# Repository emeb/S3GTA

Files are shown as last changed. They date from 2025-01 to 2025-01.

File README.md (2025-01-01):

# S3GTA
A Eurorack effects module based on the ESP32S3

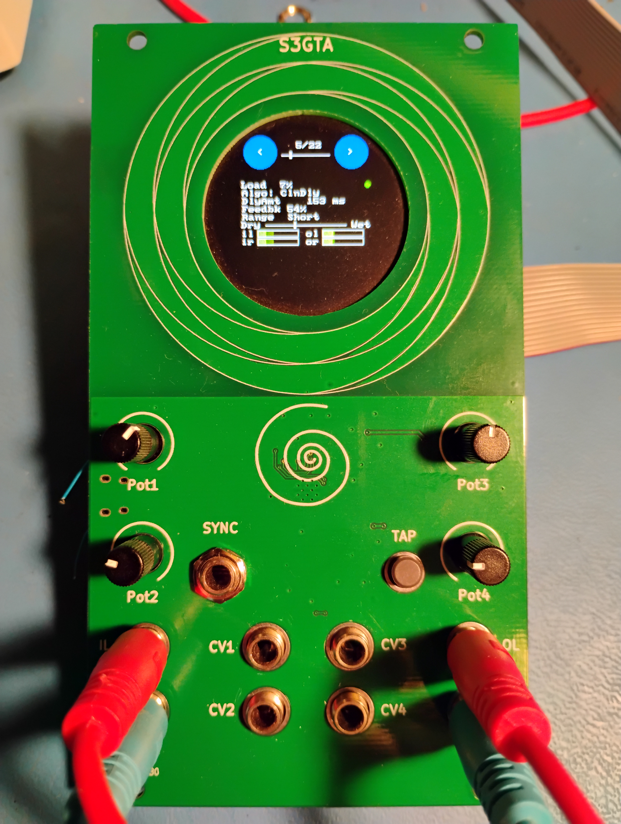
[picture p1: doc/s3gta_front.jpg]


## Abstract
This project builds on my previous ESP32S2 design:

https://github.com/emeb/ESP32S2_Audio

taking it further with a circular LCD, touch sensing and more CV inputs. It's
based on an ESP32S3 with 4MB flash and 2MB PSRAM in the package, as well as
dual CPU cores to potentially provide more DSP bandwidth.

### What's with the name?
I'm terrible at coming up with catchy names for my projects and this one is no
departure from that. It breaks down thus:
* S3 from the ESP32S3 processor
* G from the GC9A01 LCD
* T from the circular touch sensor
* A from audio I/O

## Hardware
The hardware consists of two PCBs - a front-panel board that provides the main
Eurorack user interface including a 240x240 circular LCD with a circular touch
sensor surrounding it and the MCU & audio codec, coupled with a back board that
includes the Eurorack power as well as audio and CV interfaces for the front-panel.

The front-panel PCB contains the following components:
* ESP32-S3FH4R2 MCU with 4MB flash and 2MB PSRAM integrated in the package
* WM8731 I2S audio codec
* 4 pad proportional circular touch sensor
* 4 CVs, stereo in/out and sync + button interfaces to back board.
* optional USB and Qwicc connectors

The back board has
* Standard Eurorack 16-pin shrouded power connector
* Four +/-5V CV inputs and associated analog signal conditioning
* Four offset pots for the CVs
* Two +/-7V Audio inputs and associated analog signal conditioning 
* Two +/-7V Audio outputs and associated analog drivers
* Tap tempo button
* Sync input jack

## Firmware
A demonstration firmware is included that exercises all of the capabilities of
the system, including the LCD, UI button, CV inputs and stereo audio I/O. It is
a basic multi-effects unit that supports a complement of audio DSP algorithms
that are easily extended by adding standardized modules to a data structure.
As provided here just three algorithms are available:
* Simple pass-thru with no processing
* Simple gain control
* Lowpass, Highpass and Bandpass filters
* Basic "clean delay" with crossfaded deglitching during delay changes.

Other algorithms have been tested including phasers, flangers, frequency shifters,
resampling delays and reverbs, but these are not publicly released at this time.

## Findings
The ESP32Ss is not bad for doing audio and the I2S driver in ESP-IDF V5.2.3 does
include good support for realtime audio processing. There are a few hiccups in
the way it works that are commented in the source code, but overall it does a
good job of supporting audio effects processing.

I found that in general the DSP on the ESP32S3 was usable, although not as
efficient as on ARM processors. Some algorithms showed significantly higher CPU
loading on the ESP32S3 than on ARM Cortex M7, even accounting for clock speed
differences. Studying the disassembly of the object code suggests that the full
DSP capability of the ESP32S3 Xtensa CPU ISA isn't being brought to bear by the
GCC compiler - for example the available multiply-accumulate instructions were
not used in cases where they may have reduced overall instruction counts.

## Future work
The UI is fairly primitive and doesn't make effective use of the circular touch
sensor. In the initial release there are only two "soft buttons" that employ
the touch sensor to select the current algorithm and this could be extended
to allow more soft buttons, deeper menuing and even continuously variable
adjustmets for things like on-board modulation.

The graphic elements on the circular LCD are also pretty tiny and hard to read
while also not taking full advantage of the available LCD area. It would be
interesting to "lean in" to the round nature of the display with more arcs
and circular UI elements. Fatter lines and larger fonts would help a lot too.
One option is to ditch the home-made graphics library I used here and try to
leverage LVGL which is available as an external module in ESP IDF - I did a
bit of research into this at the outset but went with my existing graphics
for ease of porting older code.

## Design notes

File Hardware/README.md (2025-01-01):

# S3GTA Hardware
This directory contains the Kicad designs for the front and back PCBs

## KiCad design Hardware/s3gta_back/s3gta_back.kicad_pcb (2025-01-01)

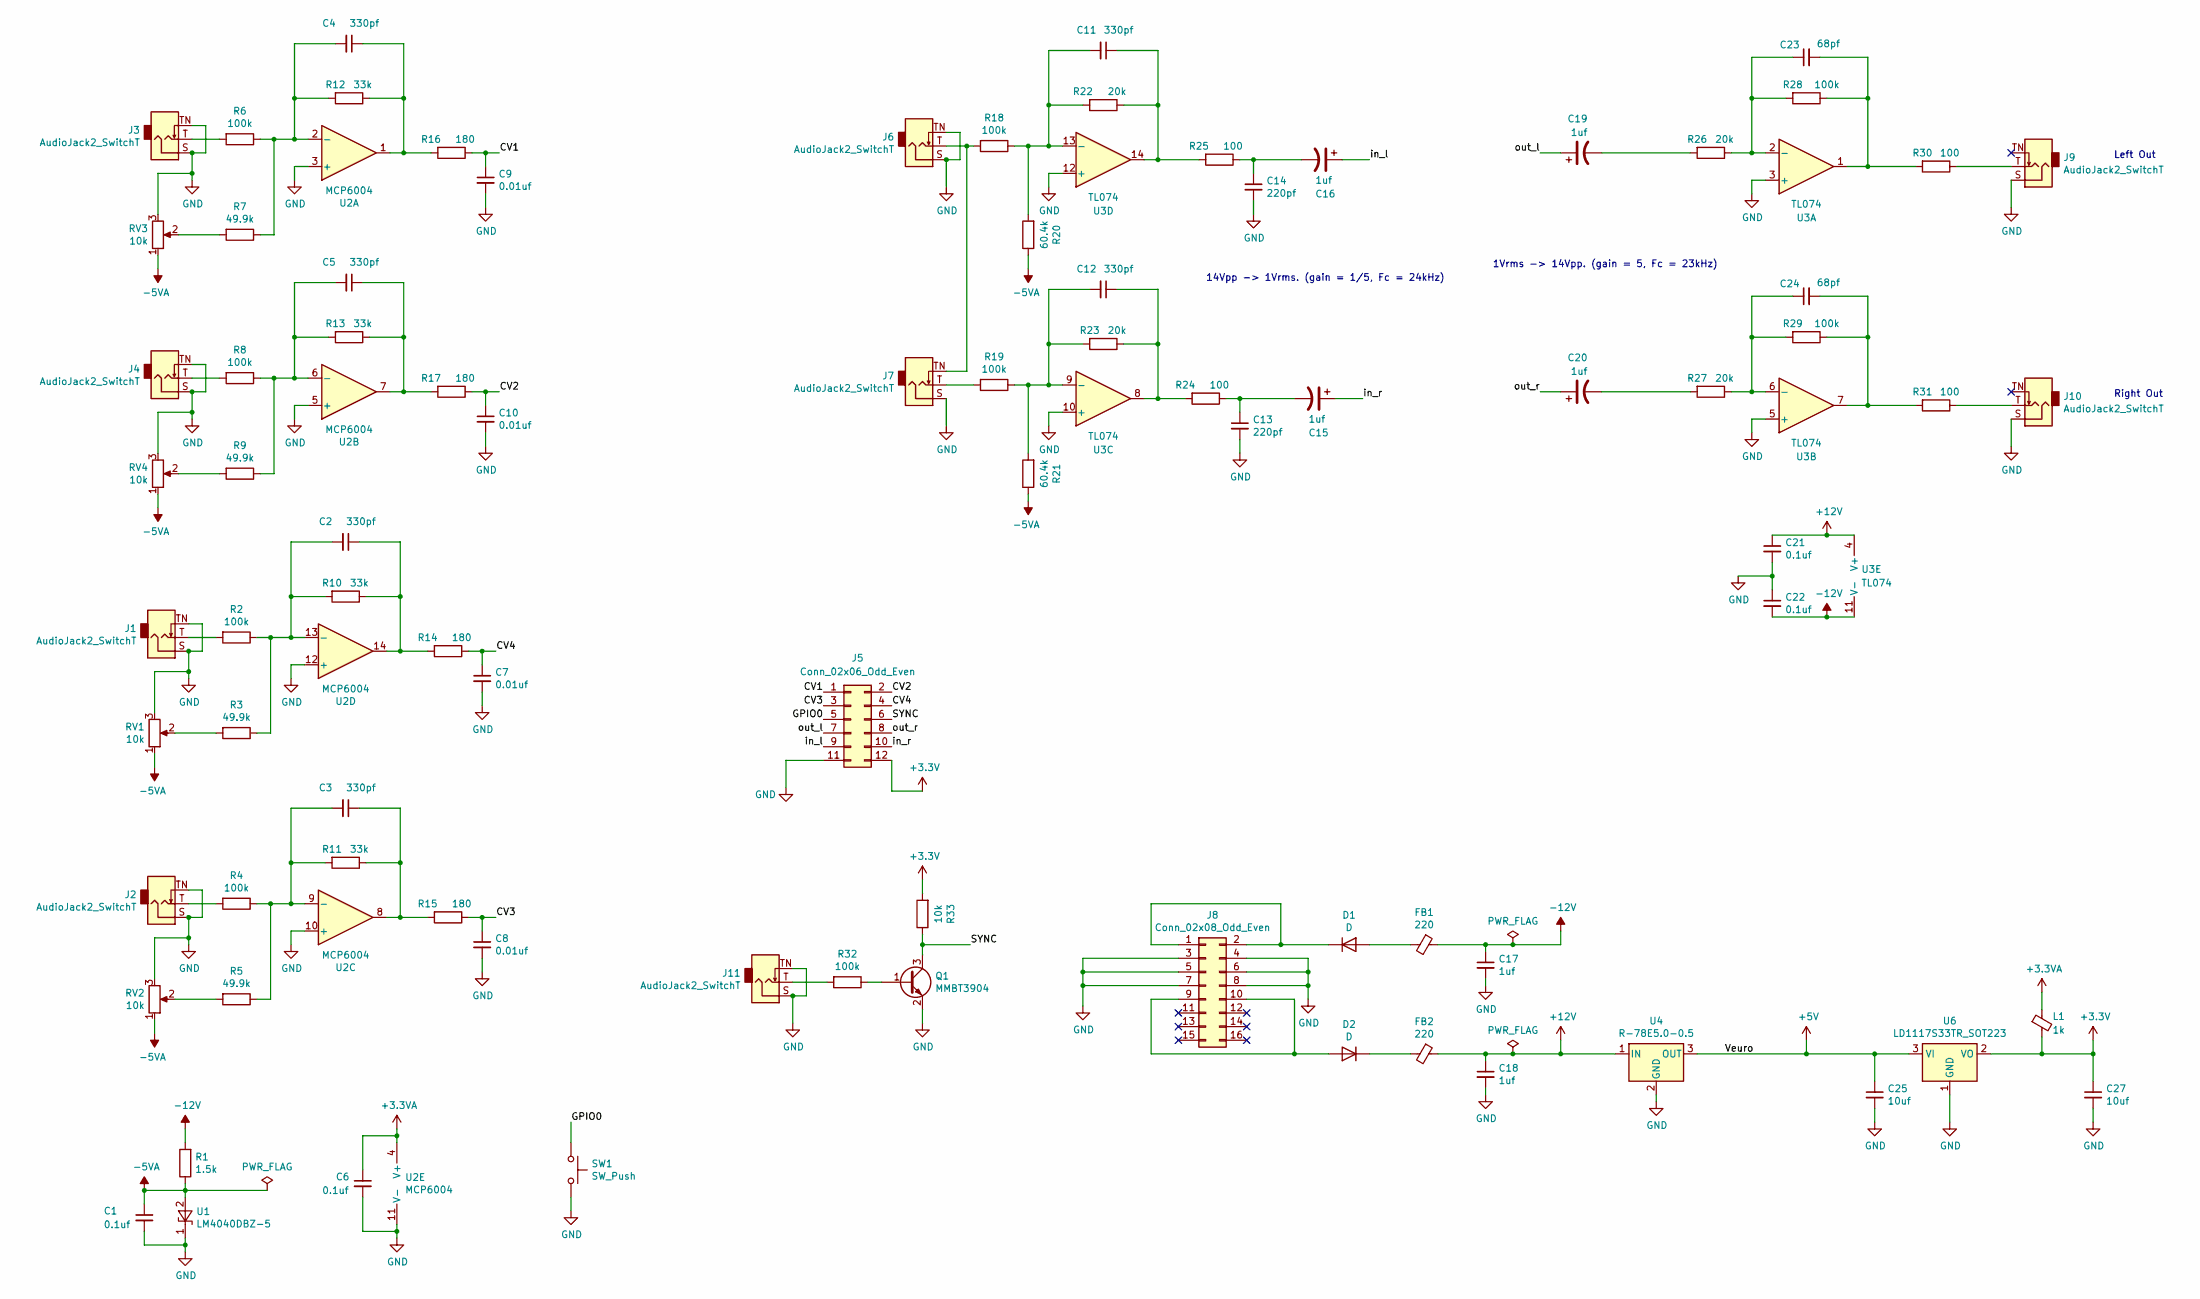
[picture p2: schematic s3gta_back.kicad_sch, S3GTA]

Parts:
C1, C6, C21, C22: 0.1uf; C_0603_1608Metric
C2, C3, C4, C5, C11, C12: 330pf; C_0603_1608Metric
C7, C8, C9, C10: 0.01uf; C_0603_1608Metric
C13, C14: 220pf; C_0603_1608Metric
C15, C16, C19, C20: 1uf; CP_Elec_4x5.3
C17, C18: 1uf; C_0603_1608Metric
C23, C24: 68pf; C_0603_1608Metric
C25, C27: 10uf; C_0805_2012Metric
D1, D2: D; D_SMA
FB1, FB2: 220; L_0805_2012Metric
J1, J2, J3, J4, J6, J7, J9, J10, J11: AudioJack2_SwitchT; Jack_3.5mm_QingPu_WQP-PJ398SM_Vertical_CircularHoles
J5: Conn_02x06_Odd_Even; PinSocket_2x06_P2.54mm_Vertical
J8: Conn_02x08_Odd_Even; con16_2X8_S4_TEC
L1: 1k; L_0603_1608Metric
Q1: MMBT3904; SOT-23
R1: 1.5k; R_0603_1608Metric
R2, R4, R6, R8, R18, R19, R28, R29, R32: 100k; R_0603_1608Metric
R3, R5, R7, R9: 49.9k; R_0603_1608Metric
R10, R11, R12, R13: 33k; R_0603_1608Metric
R14, R15, R16, R17: 180; R_0603_1608Metric
R20, R21: 60.4k; R_0603_1608Metric
R22, R23, R26, R27: 20k; R_0603_1608Metric
R24, R25, R30, R31: 100; R_0603_1608Metric
R33: 10k; R_0603_1608Metric
RV1, RV2, RV3, RV4: 10k; R0904N
SW1: SW_Push; SW_PUSH_6mm
U1: LM4040DBZ-5; SOT-23
U2: MCP6004; SOIC-14_3.9x8.7mm_P1.27mm
U3: TL074; SOIC-14_3.9x8.7mm_P1.27mm
U4: R-78E5.0-0.5; Converter_DCDC_RECOM_R-78E-0.5_THT
U6: LD1117S33TR_SOT223; SOT-223-3_TabPin2

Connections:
+3.3V: C27.1, J5.12, L1.2, R33.2, U6.2 (VO)
+3.3VA: C6.1, L1.1, U2.4 (V+)
+5V: C25.1, U4.3 (OUT), U6.3 (VI)
+12V: C18.1, C21.1, FB2.1, U3.4 (V+), U4.1 (IN)
-5VA: C1.1, R1.1, R20.1, R21.1, RV1.1, RV2.1, RV3.1, RV4.1, U1.2 (A)
-12V: C17.1, C22.2, FB1.1, R1.2, U3.11 (V-)
/CV1: C9.1, J5.1, R16.1
/CV2: C10.1, J5.2, R17.1
/CV3: C8.1, J5.3, R15.1
/CV4: C7.1, J5.4, R14.1
/GPIO0: J5.5, SW1.1
/SYNC: J5.6, Q1.3 (C), R33.1
/in_l: C16.1, J5.9
/in_r: C15.1, J5.10
/out_l: C19.1, J5.7
/out_r: C20.1, J5.8
GND: C1.2, C6.2, C7.2, C8.2, C9.2, C10.2, C13.2, C14.2, C17.2, C18.2, C21.2, C22.1, C25.2, C27.2, J1.S, J1.TN, J2.S, J2.TN, J3.S, J3.TN, J4.S, J4.TN, J5.11, J6.S, J6.TN, J7.S, J8.3, J8.4, J8.5, J8.6, J8.7, J8.8, J9.S, J10.S, J11.S, J11.TN, Q1.2 (E), RV1.3, RV2.3, RV3.3, RV4.3, SW1.2, U1.1 (K), U2.3 (+), U2.5 (+), U2.10 (+), U2.11 (V-), U2.12 (+), U3.3 (+), U3.5 (+), U3.10 (+), U3.12 (+), U4.2 (GND), U6.1 (GND)
unnamed: C2.1, R10.1, R14.2, U2.14
unnamed: C3.1, R11.1, R15.2, U2.8
unnamed: C4.1, R12.1, R16.2, U2.1
unnamed: C5.1, R13.1, R17.2, U2.7
unnamed: C11.1, R22.1, R25.2, U3.14
unnamed: C12.1, R23.1, R24.2, U3.8
unnamed: C13.1, C15.2, R24.1
unnamed: C14.1, C16.2, R25.1
unnamed: C19.2, R26.2
unnamed: C20.2, R27.2
unnamed: C23.2, R28.1, R30.2, U3.1
unnamed: C24.2, R29.1, R31.2, U3.7
unnamed: D1.2 (A), FB1.2
unnamed: D1.1 (K), J8.1, J8.2
unnamed: D2.2 (A), J8.9, J8.10
unnamed: D2.1 (K), FB2.2
unnamed: J1.T, R2.2
unnamed: J2.T, R4.2
unnamed: J3.T, R6.2
unnamed: J4.T, R8.2
unnamed: J6.T, J7.TN, R18.2
unnamed: J7.T, R19.2
unnamed: J9.T, R30.1
unnamed: J10.T, R31.1
unnamed: J11.T, R32.2
unnamed: Q1.1 (B), R32.1
unnamed: R3.2, RV1.2
unnamed: R5.2, RV2.2
unnamed: R7.2, RV3.2
unnamed: R9.2, RV4.2
unnamed: C4.2, R6.1, R7.1, R12.2, U2.2 (-)
unnamed: C5.2, R8.1, R9.1, R13.2, U2.6 (-)
unnamed: C3.2, R4.1, R5.1, R11.2, U2.9 (-)
unnamed: C2.2, R2.1, R3.1, R10.2, U2.13 (-)
unnamed: C23.1, R26.1, R28.2, U3.2 (-)
unnamed: C24.1, R27.1, R29.2, U3.6 (-)
unnamed: C12.2, R19.1, R21.2, R23.2, U3.9 (-)
unnamed: C11.2, R18.1, R20.2, R22.2, U3.13 (-)

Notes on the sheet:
1Vrms -> 14Vpp. (gain = 5, Fc = 23kHz)
14Vpp -> 1Vrms. (gain = 1/5, Fc = 24kHz)
Right Out
Left Out

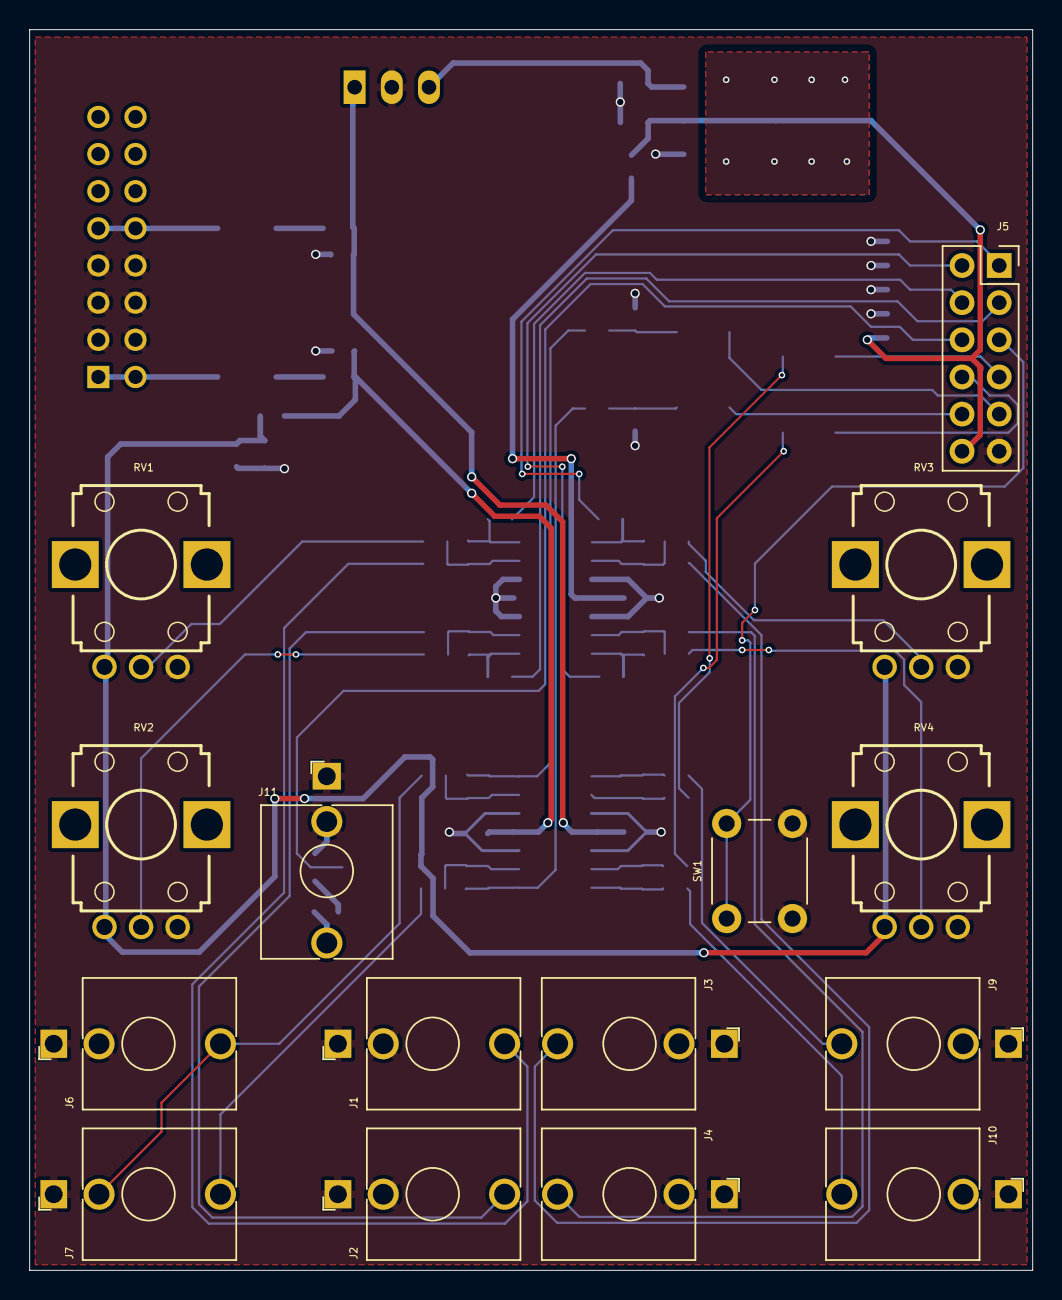
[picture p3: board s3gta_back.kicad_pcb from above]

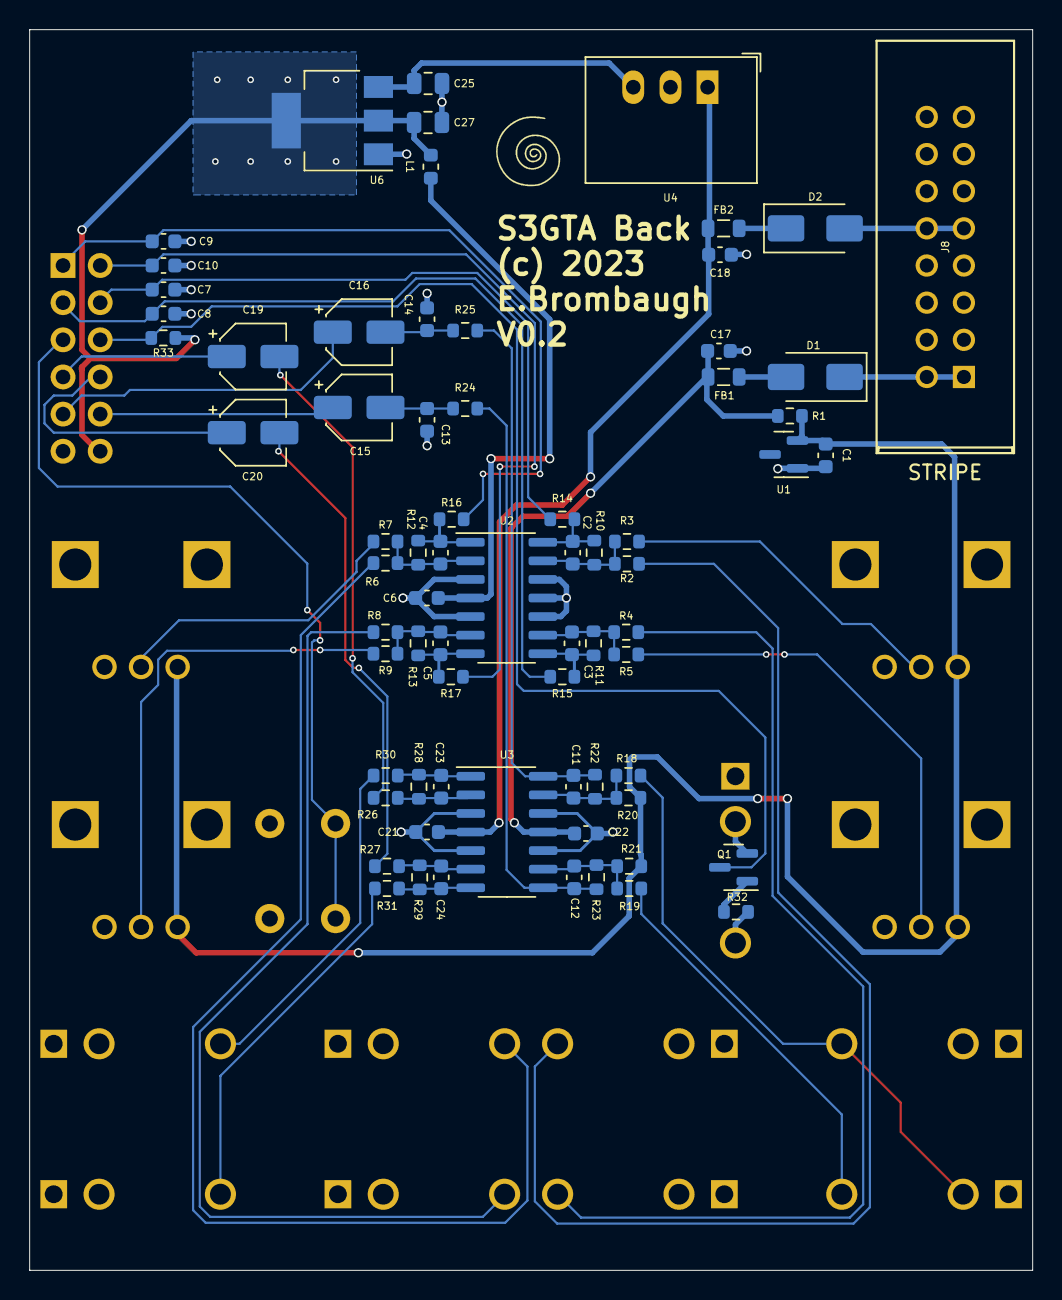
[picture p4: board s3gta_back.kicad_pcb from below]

Board: 2 copper layers, 68.6 x 84.8 mm, 87 parts (72 on the bottom side), 55 nets.

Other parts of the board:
Ref**: Val**; avatar_small

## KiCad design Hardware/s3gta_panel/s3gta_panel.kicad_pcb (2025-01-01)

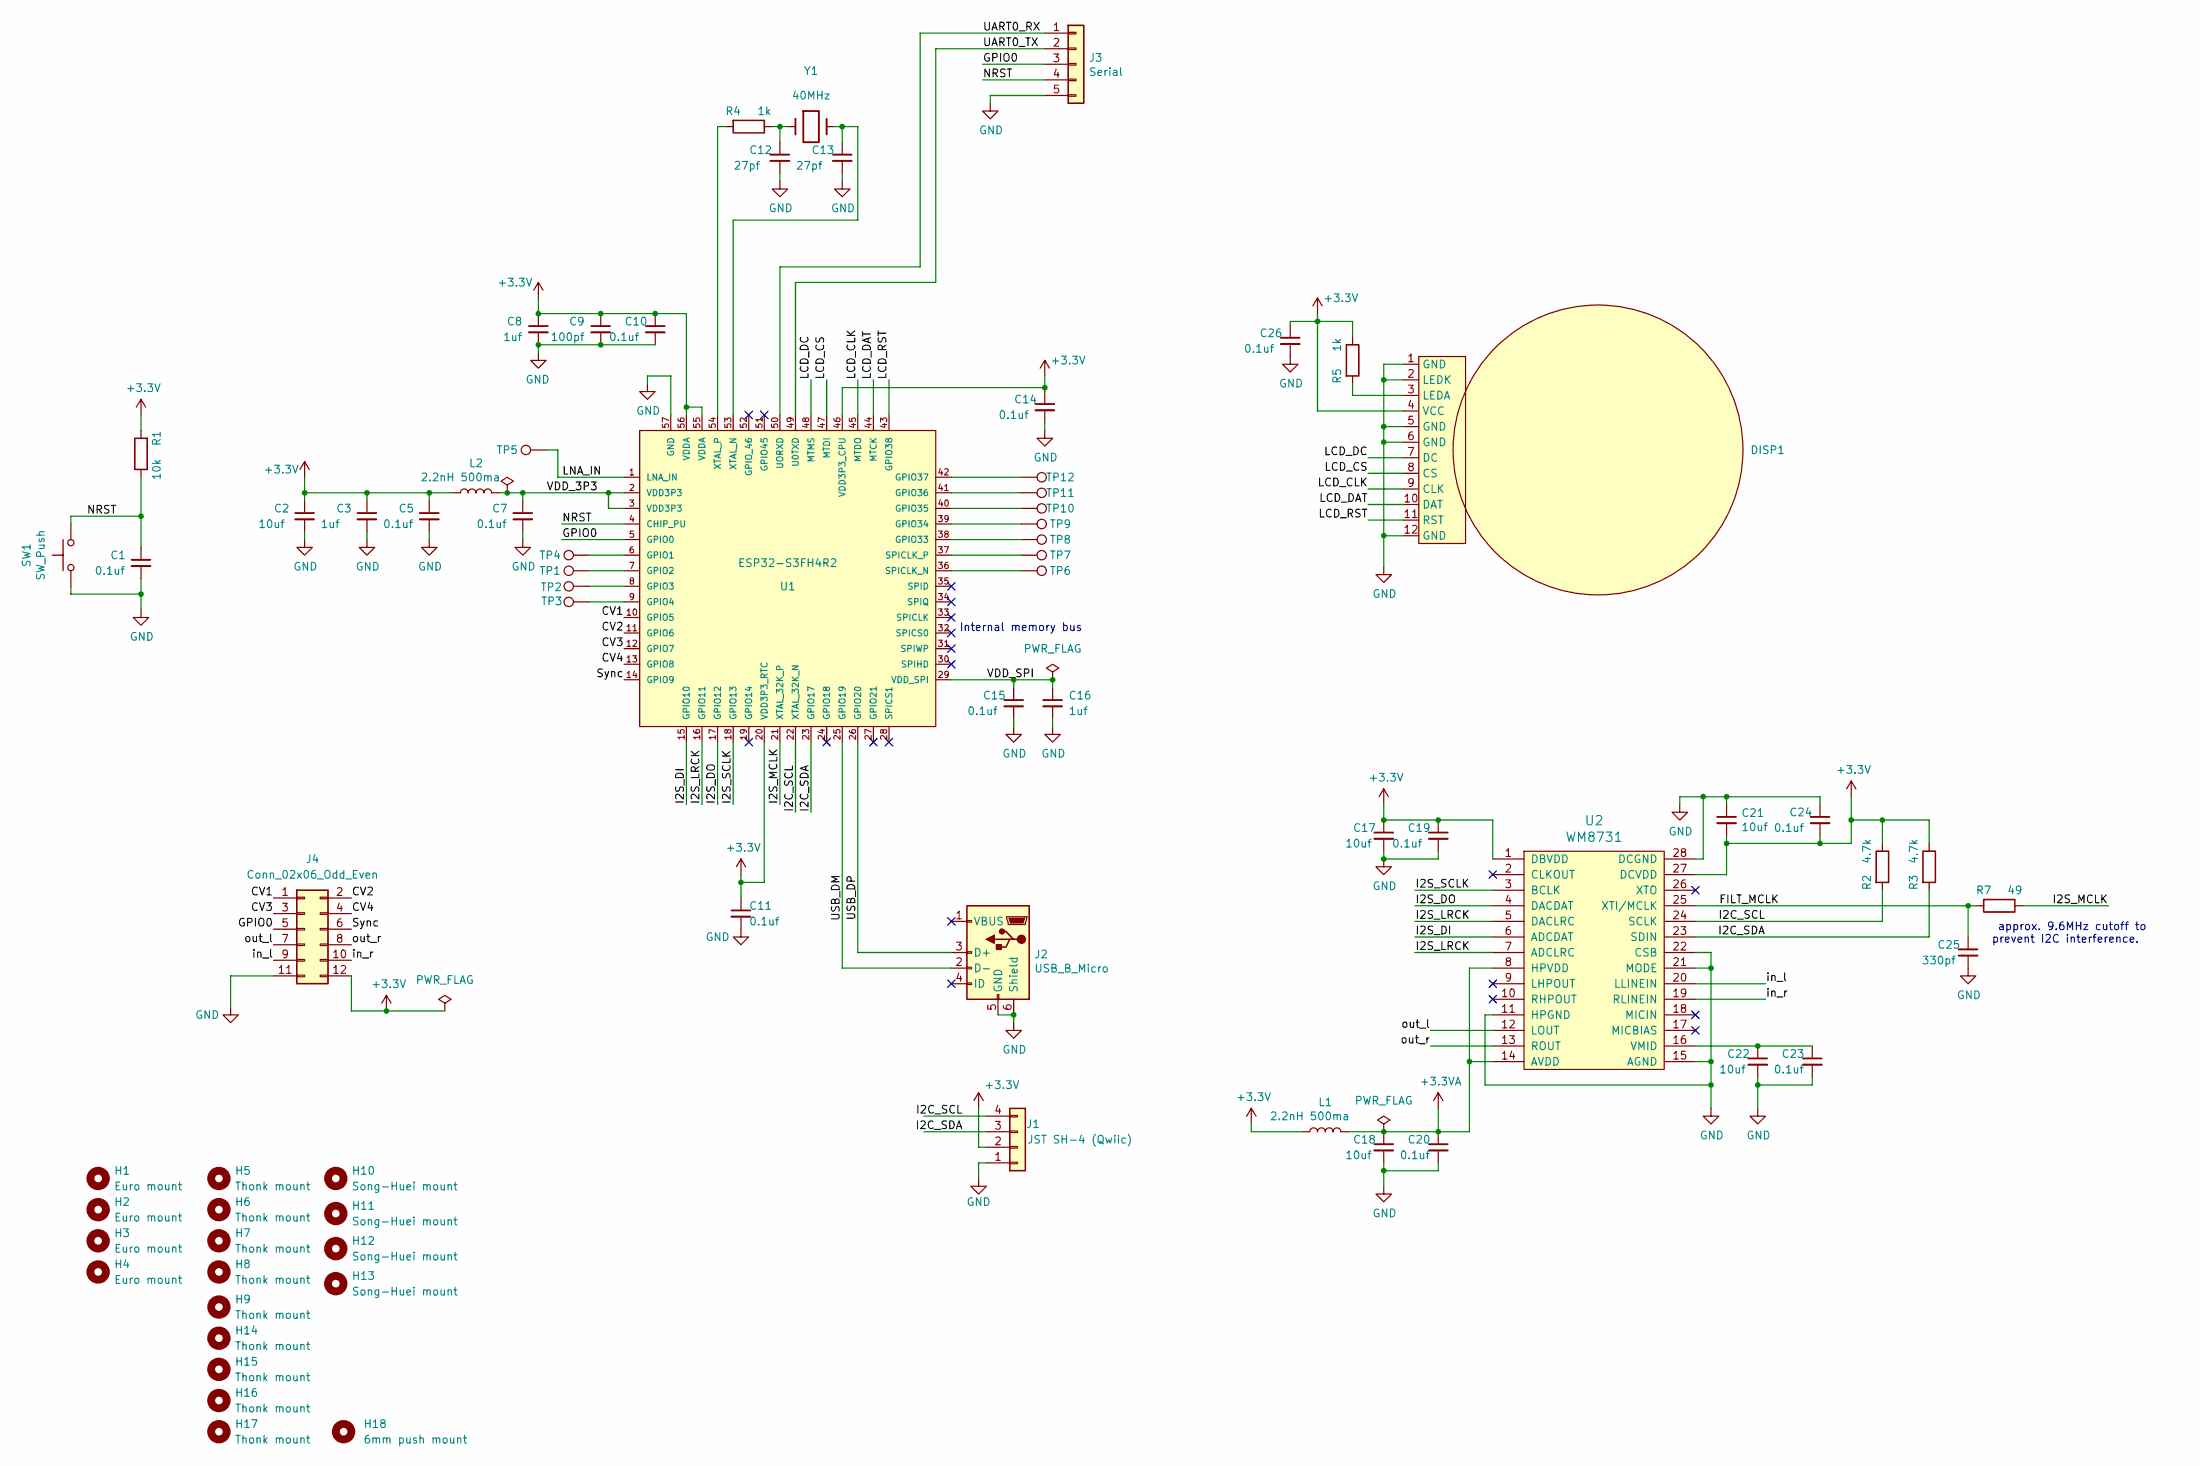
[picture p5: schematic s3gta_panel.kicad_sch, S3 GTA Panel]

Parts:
C1, C5, C7, C10, C11, C14, C15, C19, C20, C23, C24, C26: 0.1uf; C_0603_1608Metric
C2, C17, C18, C21, C22: 10uf; C_0805_2012Metric
C3, C8, C16: 1uf; C_0603_1608Metric
C9: 100pf; C_0603_1608Metric
C12, C13: 27pf; C_0603_1608Metric
C25: 330pf; C_0603_1608Metric
DISP1: Round_LCD_GC9A01
H1, H2, H3, H4: Euro mount; Mount_Hole_Euro_Rack
H5, H6, H7, H8, H9, H14, H15, H16, H17: Thonk mount; Mount_Hole_Thonk
H10, H11, H12, H13: Song-Huei mount; Mount_Hole_Song_Huei
H18: 6mm push mount; Mount_Hole_Toggle_Submini
J1: JST SH-4 (Qwiic); JST_SH_SM04B-SRSS-TB_04x1.00mm_Angled
J2: USB_B_Micro; USB_Micro-B_10103594-0001LF_actual_outline
J3: Serial; Harwin_M20-89005xx_1x05_P2.54mm_Horizontal
J4: Conn_02x06_Odd_Even; PinHeader_2x06_P2.54mm_Vertical_SMD
L1, L2: 2.2nH 500ma; C_0603_1608Metric
R1: 10k; R_0603_1608Metric
R2, R3: 4.7k; R_0603_1608Metric
R4, R5: 1k; R_0603_1608Metric
R7: 49; R_0603_1608Metric
SW1: SW_Push; SW_Push_1P1T_NO_CK_KMR2
TP1, TP2, TP3, TP4: TouchPad; quarter_touch
TP5, TP6, TP7, TP8, TP9, TP10, TP11, TP12: TouchPad; TestPoint_Pad_D0.5mm
U1: ESP32-S3FH4R2; ESP32-S3; mouser part number 356-ESP32-S2; digikey description RX TXRX MOD WIFI SURFACE MOUNT
U2: WM8731; SSOP-28_5.3x10.2mm_P0.65mm
Y1: 40MHz; Crystal_SMD_3225-4Pin_3.2x2.5mm

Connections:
+3.3V: C2.1, C3.1, C5.1, C8.1, C9.1, C10.1, C11.1, C14.1, C17.1, C19.1, C21.2, C24.2, C26.1, DISP1.4 (VCC), J1.2, J4.12, L1.1, L2.1, R1.2, R2.1, R3.1, R5.1, U1.20 (VDD3P3_RTC), U1.46 (VDD3P3_CPU), U1.55 (VDDA), U1.56 (VDDA), U2.1 (DBVDD), U2.27 (DCVDD)
+3.3VA: C18.1, C20.1, L1.2, U2.8 (HPVDD), U2.14 (AVDD)
/CV1: J4.1, U1.10 (GPIO5)
/CV2: J4.2, U1.11 (GPIO6)
/CV3: J4.3, U1.12 (GPIO7)
/CV4: J4.4, U1.13 (GPIO8)
/FILT_MCLK: C25.1, R7.2, U2.25 (XTI/MCLK)
/GPIO0: J3.3, J4.5, U1.5 (GPIO0)
/I2C_SCL: J1.4, R2.2, U1.22 (XTAL_32K_N), U2.24 (SCLK)
/I2C_SDA: J1.3, R3.2, U1.23 (GPIO17), U2.23 (SDIN)
/I2S_DI: U1.15 (GPIO10), U2.6 (ADCDAT)
/I2S_DO: U1.17 (GPIO12), U2.4 (DACDAT)
/I2S_LRCK: U1.16 (GPIO11), U2.5 (DACLRC), U2.7 (ADCLRC)
/I2S_MCLK: R7.1, U1.21 (XTAL_32K_P)
/I2S_SCLK: U1.18 (GPIO13), U2.3 (BCLK)
/LCD_CLK: DISP1.9 (CLK), U1.45 (MTDO)
/LCD_CS: DISP1.8 (CS), U1.47 (MTDI)
/LCD_DAT: DISP1.10 (DAT), U1.44 (MTCK)
/LCD_DC: DISP1.7 (DC), U1.48 (MTMS)
/LCD_RST: DISP1.11 (RST), U1.43 (GPIO38)
/LNA_IN: TP5.1, U1.1 (LNA_IN)
/NRST: C1.1, J3.4, R1.1, SW1.1, U1.4 (CHIP_PU)
/Sync: J4.6, U1.14 (GPIO9)
/UART0_RX: J3.1, U1.50 (UORXD)
/UART0_TX: J3.2, U1.49 (U0TXD)
/USB_DM: J2.2 (D-), U1.25 (GPIO19)
/USB_DP: J2.3 (D+), U1.26 (GPIO20)
/VDD_3P3: C7.1, L2.2, U1.2 (VDD3P3), U1.3 (VDD3P3)
/VDD_SPI: C15.1, C16.1, U1.29 (VDD_SPI)
/in_l: J4.9, U2.20 (LLINEIN)
/in_r: J4.10, U2.19 (RLINEIN)
/out_l: J4.7, U2.12 (LOUT)
/out_r: J4.8, U2.13 (ROUT)
GND: C1.2, C2.2, C3.2, C5.2, C7.2, C8.2, C9.2, C10.2, C11.2, C12.2, C13.2, C14.2, C15.2, C16.2, C17.2, C18.2, C19.2, C20.2, C21.1, C22.2, C23.2, C24.1, C25.2, C26.2, DISP1.1 (GND), DISP1.2 (LEDK), DISP1.5 (GND), DISP1.6 (GND), DISP1.12 (GND), J1.1, J2.5 (GND), J2.6 (Shield), J3.5, J4.11, SW1.2, U1.57 (GND), U2.11 (HPGND), U2.15 (AGND), U2.21 (MODE), U2.22 (CSB), U2.28 (DCGND)
unnamed: C12.1, R4.1, Y1.1
unnamed: DISP1.3 (LEDA), R5.2
unnamed: TP4.1, U1.6 (GPIO1)
unnamed: TP1.1, U1.7 (GPIO2)
unnamed: TP2.1, U1.8 (GPIO3)
unnamed: TP3.1, U1.9 (GPIO4)
unnamed: TP8.1, U1.38 (GPIO33)
unnamed: TP9.1, U1.39 (GPIO34)
unnamed: TP10.1, U1.40 (GPIO35)
unnamed: TP11.1, U1.41 (GPIO36)
unnamed: TP12.1, U1.42 (GPIO37)
unnamed: TP6.1, U1.36 (SPICLK_N)
unnamed: TP7.1, U1.37 (SPICLK_P)
unnamed: C13.1, U1.53 (XTAL_N), Y1.3
unnamed: R4.2, U1.54 (XTAL_P)
unnamed: C22.1, C23.1, U2.16 (VMID)

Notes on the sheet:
Internal memory bus
approx. 9.6MHz cutoff to prevent I2C interference.

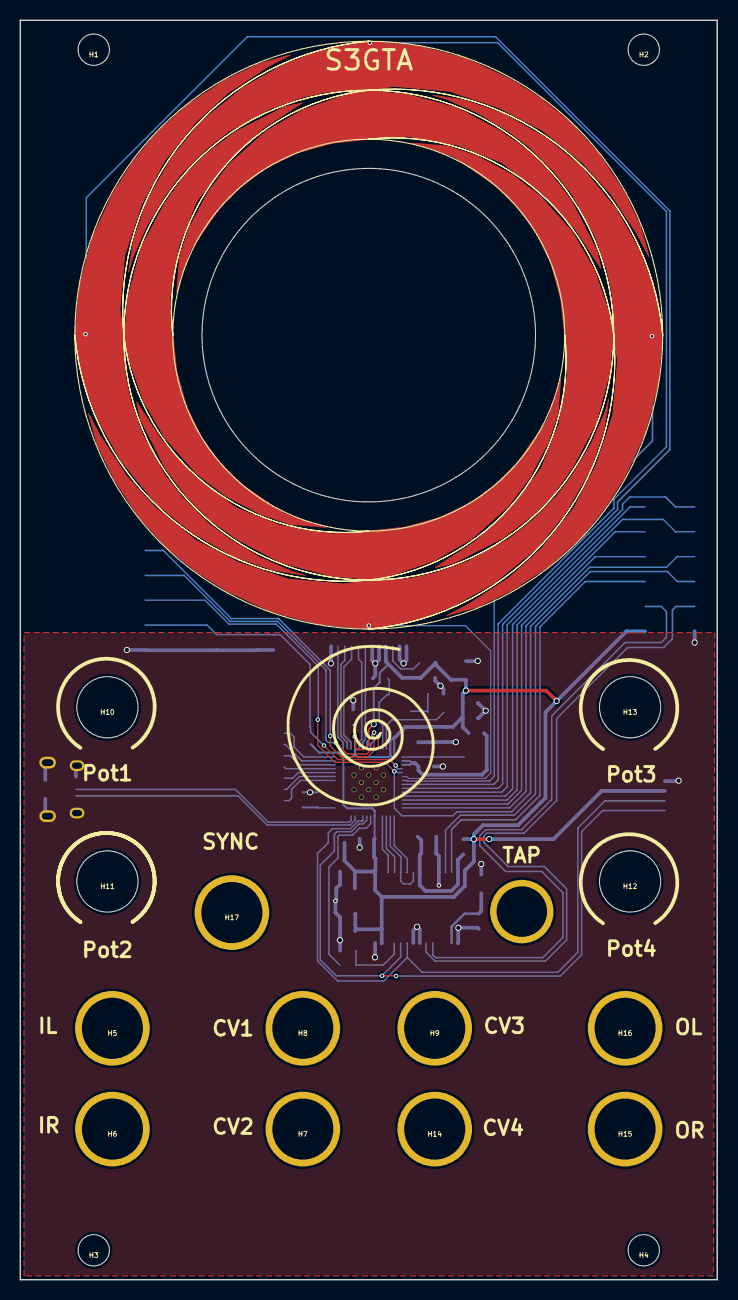
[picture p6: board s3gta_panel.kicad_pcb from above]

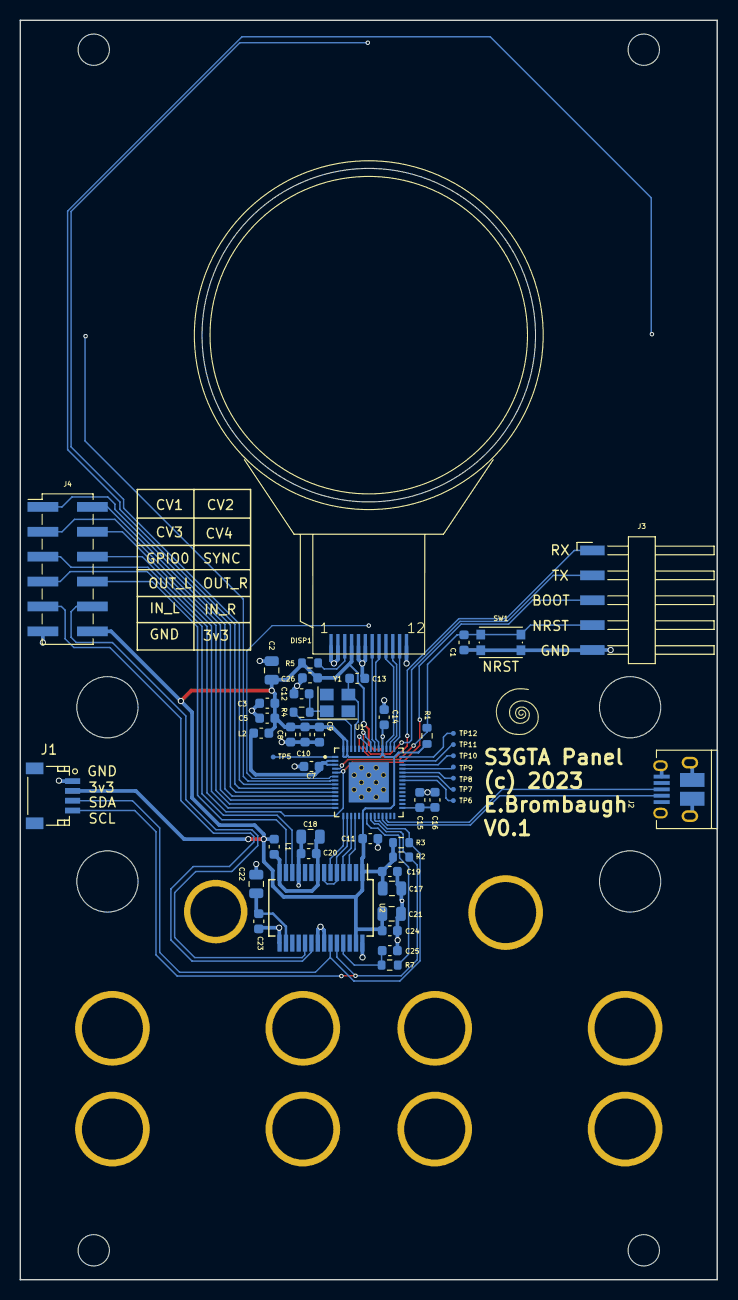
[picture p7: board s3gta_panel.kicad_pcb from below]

Board: 2 copper layers, 71.1 x 128.5 mm, 73 parts (50 on the bottom side), 50 nets.

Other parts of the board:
Ref**: Val**; avatar
Ref**#2: Val**; avatar_small

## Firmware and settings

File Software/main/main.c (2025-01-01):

/*
 * main.c - top level of s3gta audio + touch module
 * 11-18-24 E. Brombaugh
 */

#include <stdio.h>
#include "main.h"
#include "gfx.h"
#include "gc9a01_drvr.h"
#include "touch_ring.h"
#include "menu.h"
#include "eb_wm8731.h"
#include "eb_i2s.h"
#include "eb_adc.h"
#include "button.h"
#include "audio.h"
#include "splash.h"
#ifdef MULTICORE
#include "multicore_audio.h"
#endif

/* tag for logging */
static const char *TAG = "main";

/* build version in simple format */
const char *fwVersionStr = "V0.1";

/* build time */
const char *bdate = __DATE__;
const char *btime = __TIME__;

/*
 * entry point
 */
void app_main(void)
{
	/* start logging of main app */
	printf("\n\nS3GTA - Audio DSP module %s starting\n\r", fwVersionStr);
	printf("Build Date: %s\n\r", bdate);
	printf("Build Time: %s\n\r", btime);
	printf("\n");
	
	/* init ADC */
    ESP_LOGI(TAG, "Init ADC");
	eb_adc_init();
	
	/* init audio */
    ESP_LOGI(TAG, "Init Audio");
#ifdef MULTICORE
	multicore_audio_init();
#else
	audio_init();
#endif
	
	/* init codec */
    ESP_LOGI(TAG, "Init WM8731 Codec");
	eb_wm8731_Init();
	eb_wm8731_Reset();
	eb_wm8731_Mute(0);
	//eb_wm8731_Bypass(1);
	
	/* init button */
    ESP_LOGI(TAG, "Init button");
	button_init();
	
	/* init the touch ring to run in background */
    ESP_LOGI(TAG, "Start Touch Ring handler");
	touch_ring_init();

	/* init the LCD and show splash screen */
    ESP_LOGI(TAG, "Init GFX with GC9A01");
	gfx_init(&GC9A01_drvr);
	gfx_set_forecolor(GFX_BLACK);
	gfx_set_backcolor(0xc7def6);
	gfx_clrscreen();
	gfx_bitblt(0, 80, 160, 80, (uint16_t *)splash_png_565);
	gfx_drawstrctr(120, 110, "S3GTA");
	gfx_drawstrctr(120, 120, "Audio");
	gfx_drawstrctr(120, 130, (char *)fwVersionStr);
	GC9A01_setBacklight(1);
	gfx_set_forecolor(GFX_WHITE);
	gfx_set_backcolor(GFX_BLACK);
	vTaskDelay(pdMS_TO_TICKS(3000));
	
	/* init menu */
    ESP_LOGI(TAG, "Init menu");
	menu_init();
	
	/* report buffer info */
	//i2s_diag();
	
	/* foreground loop just handles menu */
    ESP_LOGI(TAG, "Looping...");
    while(1)
	{
		menu_update();
		
        vTaskDelay(pdMS_TO_TICKS(20));
    }
}

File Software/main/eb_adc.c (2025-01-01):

/*
 * eb_adc.c - my high-level ADC driver. Mimics background ADC operation.
 * 01-16-22 E. Brombaugh
 */
 
#include <stdio.h>
#include "main.h"
//#include "driver/adc.h"
#include "esp_adc/adc_oneshot.h"
#include "driver/gpio.h"
#include "esp_timer.h"
#include "hal/i2s_hal.h"
#include "hal/i2s_types.h"
#include <soc/sens_reg.h>
#include <soc/sens_struct.h>
#include <soc/spi_reg.h>
#include <soc/spi_struct.h>
#include "eb_adc.h"

static const char* TAG = "eb_adc";
static uint8_t adc_idx, adc_hyst_state, adc_param_idx;
//static int16_t adc_hyst_val;
int32_t adc_iir[ADC_NUMVALS];
volatile int16_t adc_val[ADC_NUMVALS], adc_param[ADC_NUMPARAMS];

#define GET_UNIT(x)			((x>>3) & 0x1)
#define TIMES				8

/*
 * channel mapping:
 * POT 1 - CV4 - GPIO8 - CHL7
 * POT 2 - CV3 - GPIO7 - CHL6
 * POT 3 - CV1 - GPIO5 - CHL4
 * POT 4 - CV2 - GPIO6 - CHL5
 */
const uint8_t adc_chls[ADC_NUMVALS] =
{
	ADC_CHANNEL_7,
	ADC_CHANNEL_6,
	ADC_CHANNEL_4,
	ADC_CHANNEL_5,	
};

/*
 * low-level: set channel, wait for ready & start conversion
 * cuts time from 45us to 15us
 */
void IRAM_ATTR my_adc1_get_raw_begin(uint8_t chl)
{
	SENS.sar_meas1_ctrl2.sar1_en_pad = (1 << chl);
	/* note that this reg is undocumented! */
	while (HAL_FORCE_READ_U32_REG_FIELD(SENS.sar_slave_addr1, meas_status) != 0) {}
	SENS.sar_meas1_ctrl2.meas1_start_sar = 0;
	SENS.sar_meas1_ctrl2.meas1_start_sar = 1;
}

/*
 * low-level: wait for eoc & fetch result
 */
int16_t IRAM_ATTR my_adc1_get_raw_end(void)
{
    while (SENS.sar_meas1_ctrl2.meas1_done_sar == 0);
    return 4095-HAL_FORCE_READ_U32_REG_FIELD(SENS.sar_meas1_ctrl2, meas1_data_sar);
}

/*
 * IIR filter for 12-bit ADC values 
 */
#define IIR_COEF 4
inline int16_t adc_IIR_filter(int32_t *filt_state, int16_t in)
{
	*filt_state += ((in<<IIR_COEF) - *filt_state )>>IIR_COEF;
	return *filt_state >> (IIR_COEF);
}

/*
 * ADC timer callback
 */
void IRAM_ATTR adc_timer_callback(void *arg)
{
	/* set ISR active flag */
	//gpio_set_level(DIAG_1, 1);
	
	/* don't wait for conversion - get previous result */
	adc_val[adc_idx] = adc_IIR_filter(&adc_iir[adc_idx], my_adc1_get_raw_end());

#if 0
	/* handle hysteresis */
	if(adc_idx<(ADC_NUMVALS-1))
	{
		/* update parameter */
		switch(adc_hyst_state)
		{
			case 0:	/* reset */
				adc_hyst_val = adc_val[1];
				adc_hyst_state = 1;
				break;
			
			case 1: /* locked & waiting for unlock */
				if(abs(adc_val[1]-adc_hyst_val) > 200)
					adc_hyst_state = 2;
				break;
			
			case 2:	/* tracking */
				adc_param[adc_param_idx] = adc_val[1];
				break;
		}
	}
#else
	/* just pass thru to params */
	adc_param[adc_idx] = adc_val[adc_idx];
#endif

	/* advance channel */
	adc_idx = (adc_idx + 1)%ADC_NUMVALS;
	
	/* start next conversion */
	my_adc1_get_raw_begin(adc_chls[adc_idx]);
	
	/* clear ISR active flag */
	//gpio_set_level(DIAG_1, 0);
}

esp_err_t eb_adc_init(void)
{
	uint8_t i;
	esp_timer_handle_t timer_handle;
	
	/* setup state */
	adc_idx = 0;
	adc_hyst_state = 0;
	adc_param_idx = 0;
	
	/* single conversions w/ timer */
#if 0
	/* OLD API is deprecated */
    ESP_LOGI(TAG, "PIO mode w/ deprecated driver");
	adc1_config_width(ADC_WIDTH_BIT_12);
	adc1_config_channel_atten(CV0, ADC_ATTEN_DB_6);
	adc1_config_channel_atten(CV1, ADC_ATTEN_DB_6);
	adc1_get_raw(CV0);
#else
	/* New one-shot API */
    ESP_LOGI(TAG, "PIO mode w/ new one-shot driver");
	/* init ADC1 */
	adc_oneshot_unit_handle_t adc1_handle;
	adc_oneshot_unit_init_cfg_t init_config1 = {
		.unit_id = ADC_UNIT_1,
		.ulp_mode = ADC_ULP_MODE_DISABLE,
	};
	ESP_ERROR_CHECK(adc_oneshot_new_unit(&init_config1, &adc1_handle));
	
	/* set up channels: GPIO 5-8 are ADC1 chls 4-7 */
	adc_oneshot_chan_cfg_t config = {
		.bitwidth = SOC_ADC_RTC_MAX_BITWIDTH,	// defaults to 12 bit on S3
		.atten = ADC_ATTEN_DB_6,
	};
	for(i=0;i<ADC_NUMVALS;i++)
		ESP_ERROR_CHECK(adc_oneshot_config_channel(adc1_handle, adc_chls[i], &config));

	/* read a channel to start ADC */
	int dummy;
	ESP_ERROR_CHECK(adc_oneshot_read(adc1_handle, adc_chls[0], &dummy));
#endif
	
	/* Timer for controlling ADC sampling intervals */
	esp_timer_create_args_t timer_args = {
		.callback = adc_timer_callback,
		.arg = NULL,
		.name = "adc_timer",
		.skip_unhandled_events = true
	};
	esp_timer_create(&timer_args, &timer_handle);
	esp_timer_start_periodic(timer_handle, 1000);
	
	return ESP_OK;
}

/*
 * set adc[1] parameter destination
 */
void eb_adc_setactparam(uint8_t idx)
{
	if(idx>=ADC_NUMPARAMS)
		return;
	
	if(idx != adc_param_idx)
	{
		/* this has to be atomic */
		taskDISABLE_INTERRUPTS();
		adc_param_idx = idx;
		adc_hyst_state = 0;
		taskENABLE_INTERRUPTS();
	}
}

/*
 * set adc[1] parameter value
 */
void eb_adc_setparamval(uint8_t idx, int16_t val)
{
	if(idx>=ADC_NUMPARAMS)
		return;
	
	adc_param[idx] = val;
}

/*
 * force adc[1] active parameter hysteresis to track live value
 */
void eb_adc_forceactparam(void)
{
	adc_hyst_state = 2;
}

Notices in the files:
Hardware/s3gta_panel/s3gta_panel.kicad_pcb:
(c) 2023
